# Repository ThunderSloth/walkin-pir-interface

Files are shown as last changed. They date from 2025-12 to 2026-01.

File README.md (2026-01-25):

# Battery-Powered PIR Motion Interface (Isolated Dry Contact)

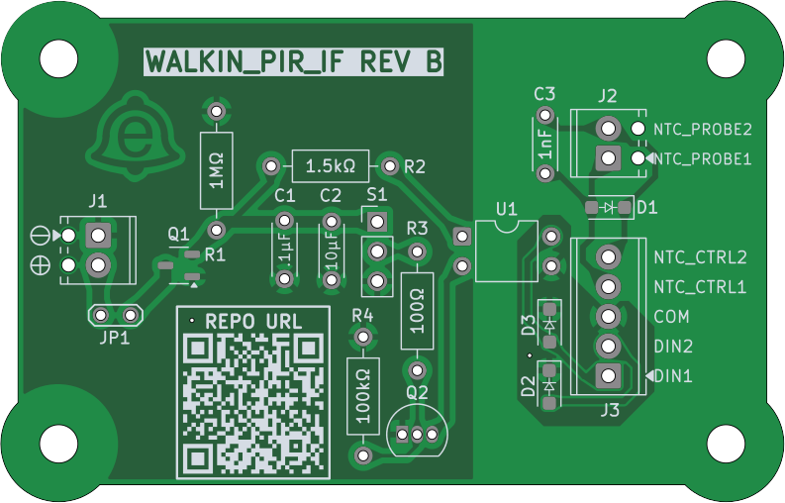
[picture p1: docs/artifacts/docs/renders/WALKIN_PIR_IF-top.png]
Top view PCB render

## Overview
Battery-powered PIR interface designed to trigger **motion-activated overhead lighting** via an **isolated dry input** on an **XWA11V industrial controller**. Intended for installation in a **walk-in cooler** where running mains power to the sensor is undesirable.

The board detects motion using an **AM312 PIR** and signals the controller by closing a **dry contact (DIN ↔ COM)** through a **PhotoMOS relay**. It also provides a **pass-through connection for an external NTC temperature probe**, allowing temperature sensing to share the same cable run.

All lighting logic and power switching are handled by the controller; this board functions as a low-power, robust peripheral.

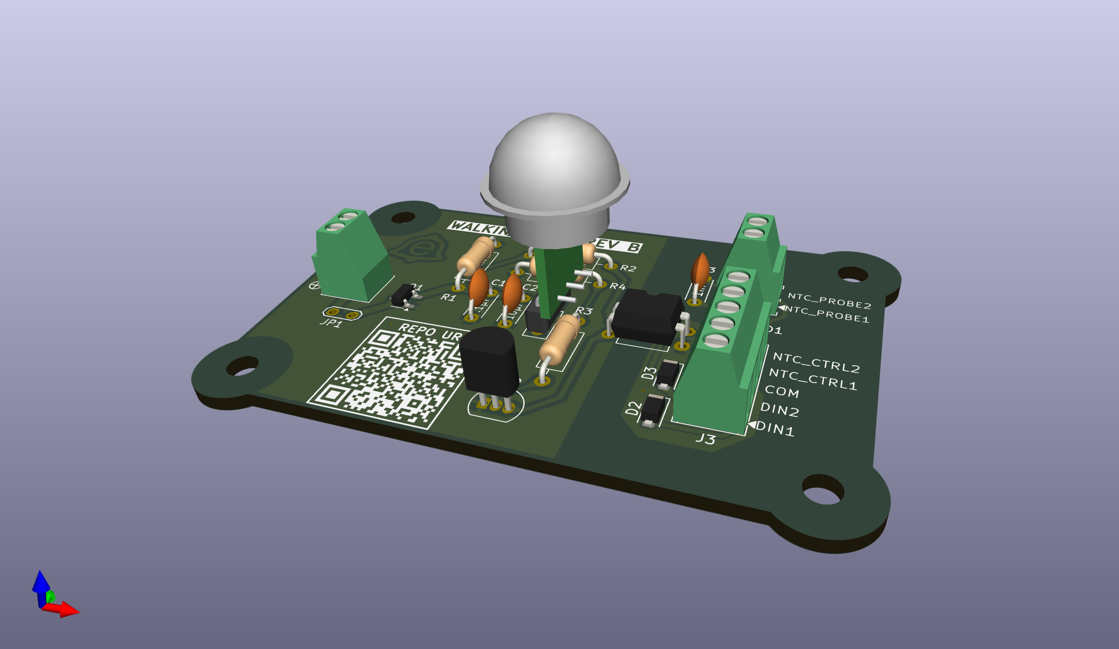
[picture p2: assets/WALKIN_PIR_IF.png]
3D render of WALKIN_PIR_IF PCB


---

## Design Summary
- **Power:** 3×AA battery (targeting multi-month to ~1 year life)
- **Isolation:** PhotoMOS relay provides a true dry contact
- **Protection:**
  - Reverse polarity protection on battery input
  - TVS diodes on all field wiring (DIN, COM, NTC probe)
- **Environment:** Cold (~35–40°F), ~6 ft cable runs
- **Assembly:** Hand-solderable THT + simple SMD parts

---

## Design Rationale
- Battery power avoids mains wiring near the sensor
- PhotoMOS isolation prevents ground loops with industrial controls
- TVS protection improves robustness for long, exposed wiring
- Conservative, low-power design prioritizes reliability over complexity

---

## Hardware Documentation

All design, assembly, and fabrication artifacts are published here:

➡️ [WALKIN_PIR_IF Documentation (MkDocs)](https://thundersloth.github.io/walkin-pir-interface/)

---

## Hardware Status

**Rev B sent to fabrication ✅**  
Simplified prototype validated (video below).

- **Rev A:** PIR output sags under direct PhotoMOS LED drive → unreliable switching.
- **Rev B:** Added NPN low-side driver + LED current-limit resistor to isolate PIR output from load.

[https://github.com/user-attachments/assets/d97296ae-1a20-4d2e-b4a4-3fdf33289da8](https://github.com/user-attachments/assets/c07f9941-2b6e-4c99-ae80-a9b624c08050)

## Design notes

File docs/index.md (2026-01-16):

# WALKIN_PIR_IF — Hardware Documentation

Battery-powered PIR motion interface providing an isolated dry contact output for an industrial controller.

<p class="theme-image">
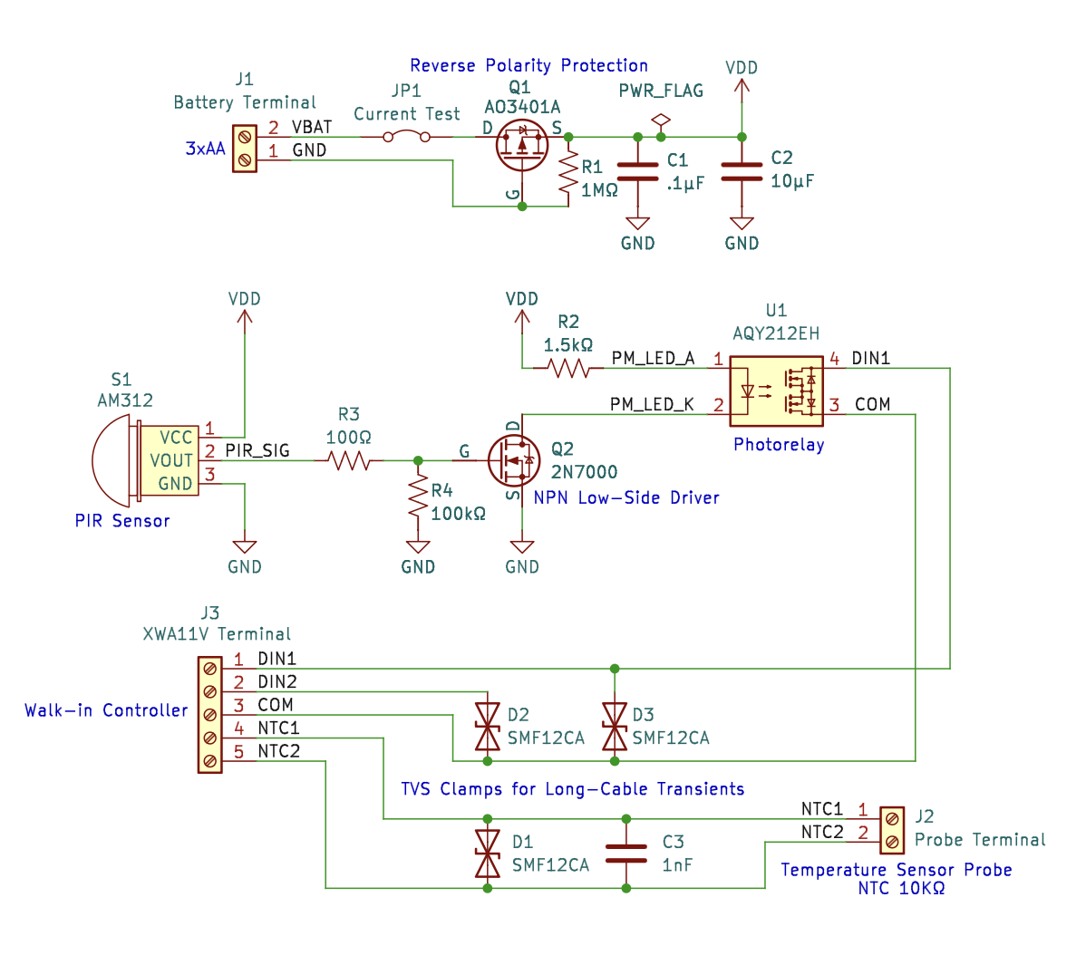
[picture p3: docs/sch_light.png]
WALKIN_PIR_IF schematic (light)
  
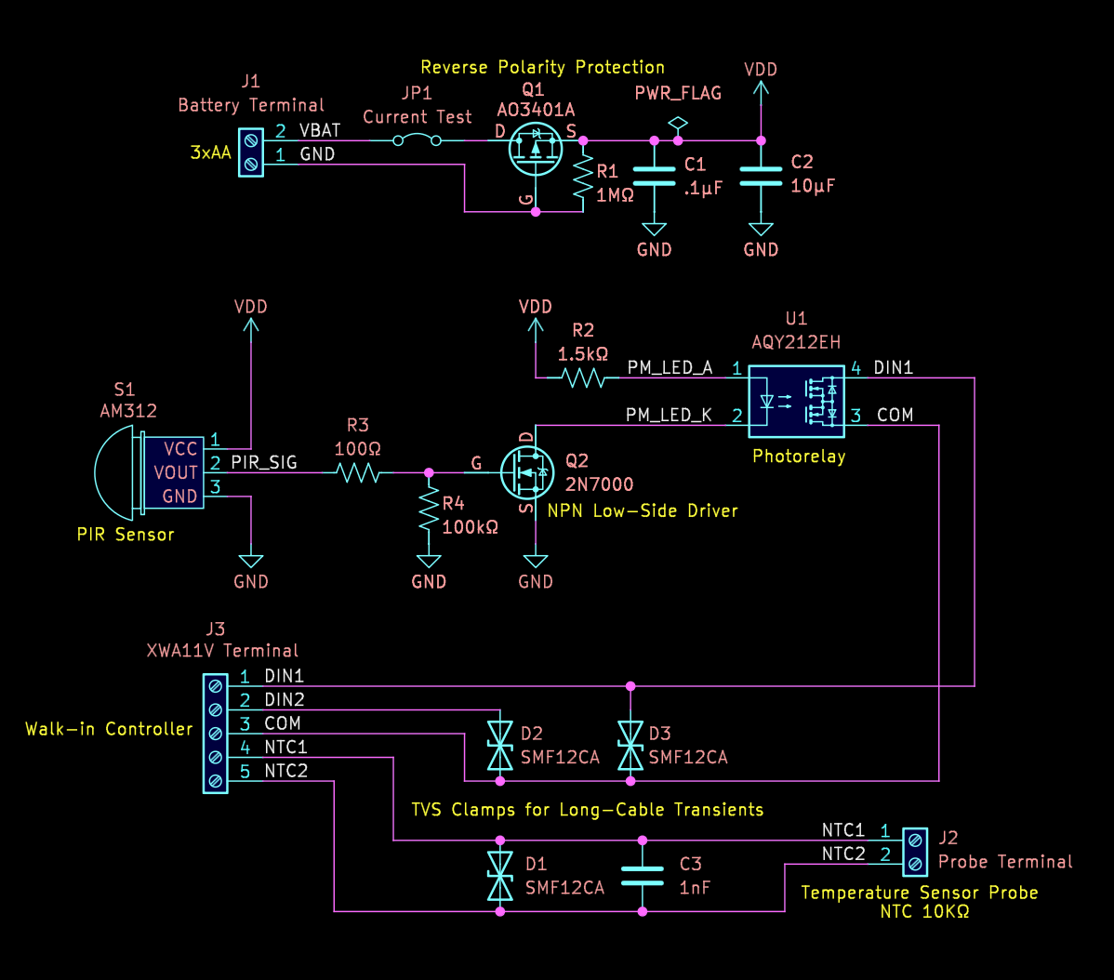
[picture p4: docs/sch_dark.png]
WALKIN_PIR_IF schematic (dark)
  
</p>

This site hosts the complete set of design, assembly, and fabrication artifacts generated from the KiCad project via KiBot.

---

## ℹ️ Project

- **GitHub Repository** [ThunderSloth/walkin-pir-interface](https://github.com/ThunderSloth/walkin-pir-interface)

---

## 📐 Design

- **Schematic (PDF)** [[view]](artifacts/docs/schematic/WALKIN_PIR_IF-schematic.pdf)
- **PCB Render — Top (2D)** [[view]](artifacts/docs/renders/WALKIN_PIR_IF-top.png)
- **PCB Render — Bottom (2D)** [[view]](artifacts/docs/renders/WALKIN_PIR_IF-bottom.png)

---

## 🔧 Assembly

- **Interactive BOM (iBOM)** [[view]](artifacts/docs/ibom/WALKIN_PIR_IF-ibom.html)
- **Bill of Materials (CSV)** [[view]](artifacts/assembly/WALKIN_PIR_IF-bom.csv.html) [[download]](artifacts/assembly/WALKIN_PIR_IF-bom.csv)
- **Pick & Place — Top Side (CSV)** [[view]](artifacts/assembly/WALKIN_PIR_IF-pickplace-top_pos.csv.html) [[download]](artifacts/assembly/WALKIN_PIR_IF-pickplace-top_pos.csv)
- **Assembly Drawing (PDF)** [[view]](artifacts/docs/assembly/WALKIN_PIR_IF-assembly-top.pdf)

---

## ⚙️ Fabrication

- **Fabrication Drawing (PDF)** [[view]](artifacts/docs/fab/WALKIN_PIR_IF-fab-drawing.pdf)
- **Gerbers & Drill Files (ZIP)** [[download]](artifacts/fab/WALKIN_PIR_IF_fab.zip)

---

## 🧊 Mechanical

- **3D STEP Model** [[download]](artifacts/mcad/WALKIN_PIR_IF-3D.step)

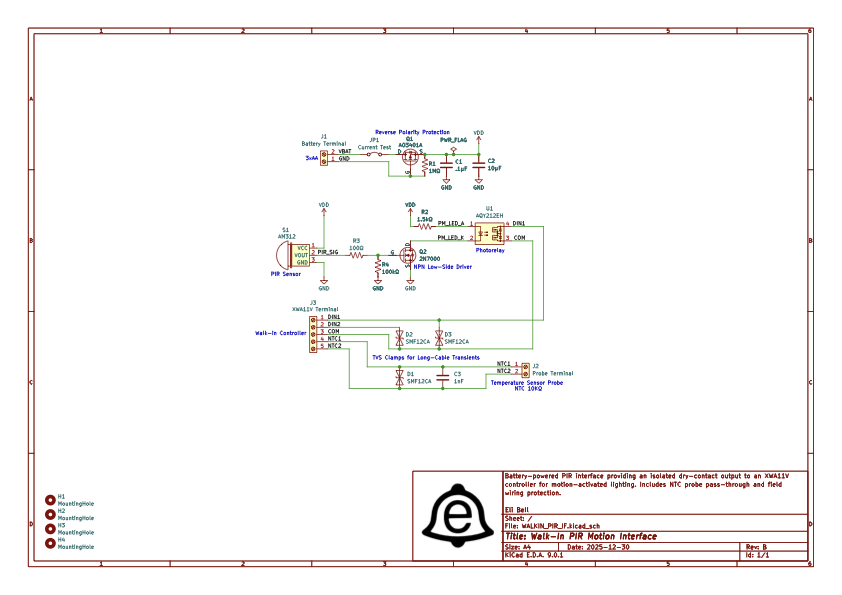
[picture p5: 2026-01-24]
docs/artifacts/previews/schematic.png

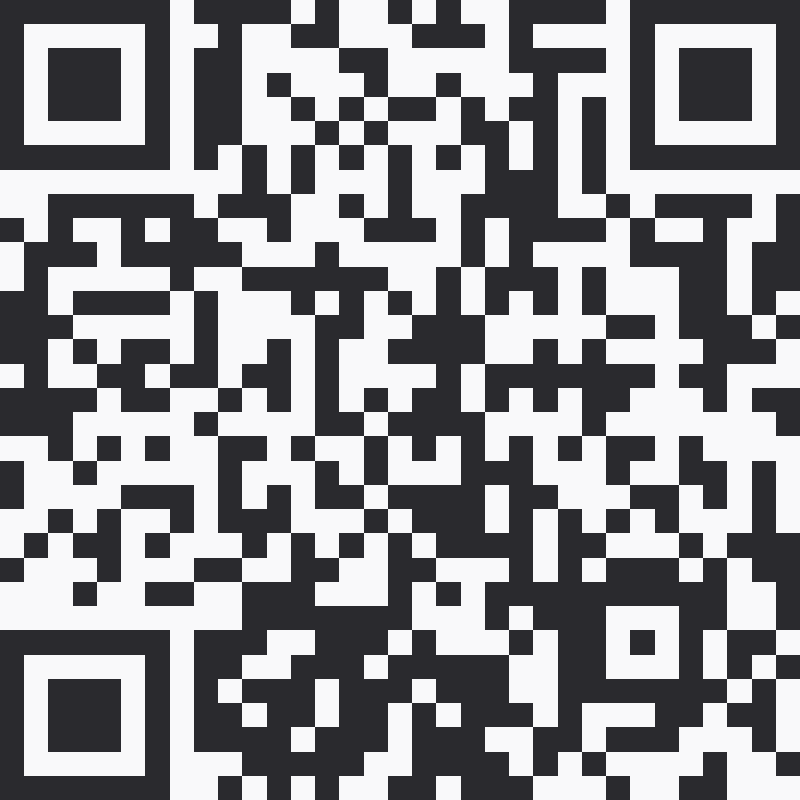
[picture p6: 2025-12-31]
assets/repo_url.png

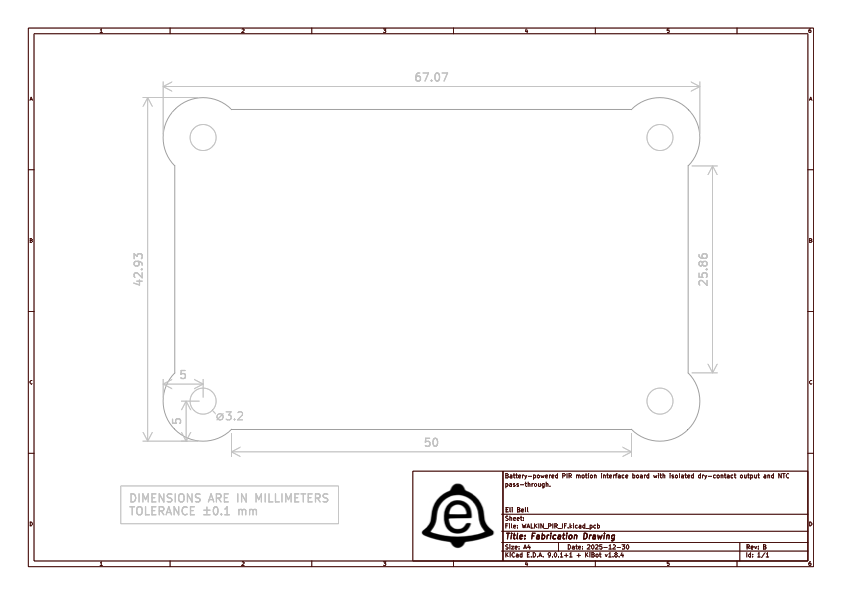
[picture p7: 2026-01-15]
docs/artifacts/previews/fab-drawing.png

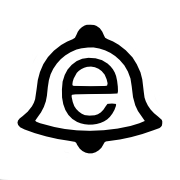
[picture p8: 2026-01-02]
assets/Eli_Bell.jpg

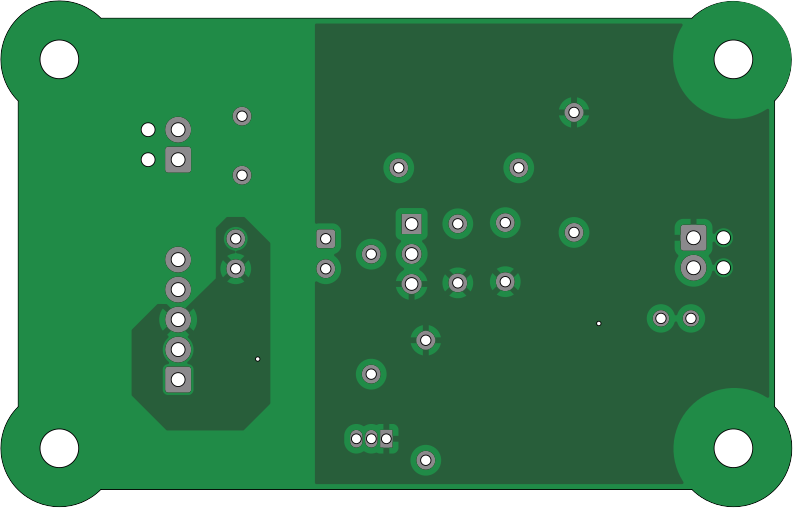
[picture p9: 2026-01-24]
docs/artifacts/docs/renders/WALKIN_PIR_IF-bottom.png

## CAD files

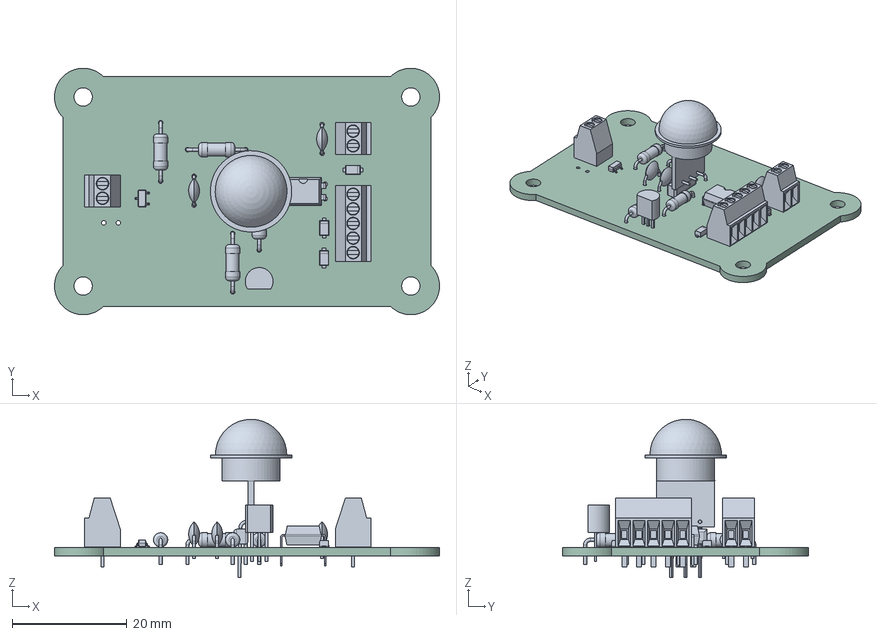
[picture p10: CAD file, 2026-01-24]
docs/artifacts/mcad/WALKIN_PIR_IF-3D.step
67.1 x 42.9 x 27.6 mm
TerminalBlock_Phoenix_MPT-0,5-5-2.54_1x05_P2.54mm_Horizontal
C_Disc_D4.3mm_W1.9mm_P5.00mm x 3
DIP-4_W7.62mm
SOT-23-3
D_SOD-123F x 3
R_Axial_DIN0207_L6.3mm_D2.5mm_P10.16mm_Horizontal_1_0_1
TerminalBlock_Phoenix_MPT-0,5-2-2.54_1x02_P2.54mm_Horizontal x 2
R_Axial_DIN0207_L6.3mm_D2.5mm_P10.16mm_Horizontal_1_0_5
R_Axial_DIN0207_L6.3mm_D2.5mm_P10.16mm_Horizontal_1_5_2
AM312
TO-92_Inline
R_Axial_DIN0207_L6.3mm_D2.5mm_P10.16mm_Horizontal_1_0_4
kibot_5gq1o4dk_PCB

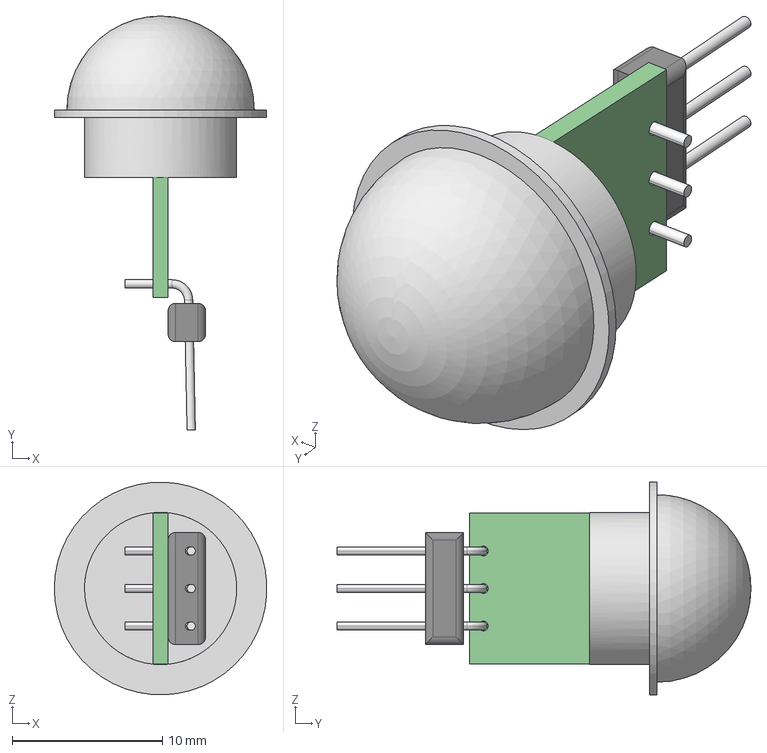
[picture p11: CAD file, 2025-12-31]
hardware/pcb/kicad/3dmodels/AM312.step
14.2 x 27.6 x 14.2 mm

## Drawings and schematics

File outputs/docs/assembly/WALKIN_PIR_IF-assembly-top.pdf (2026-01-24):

67.07

H4

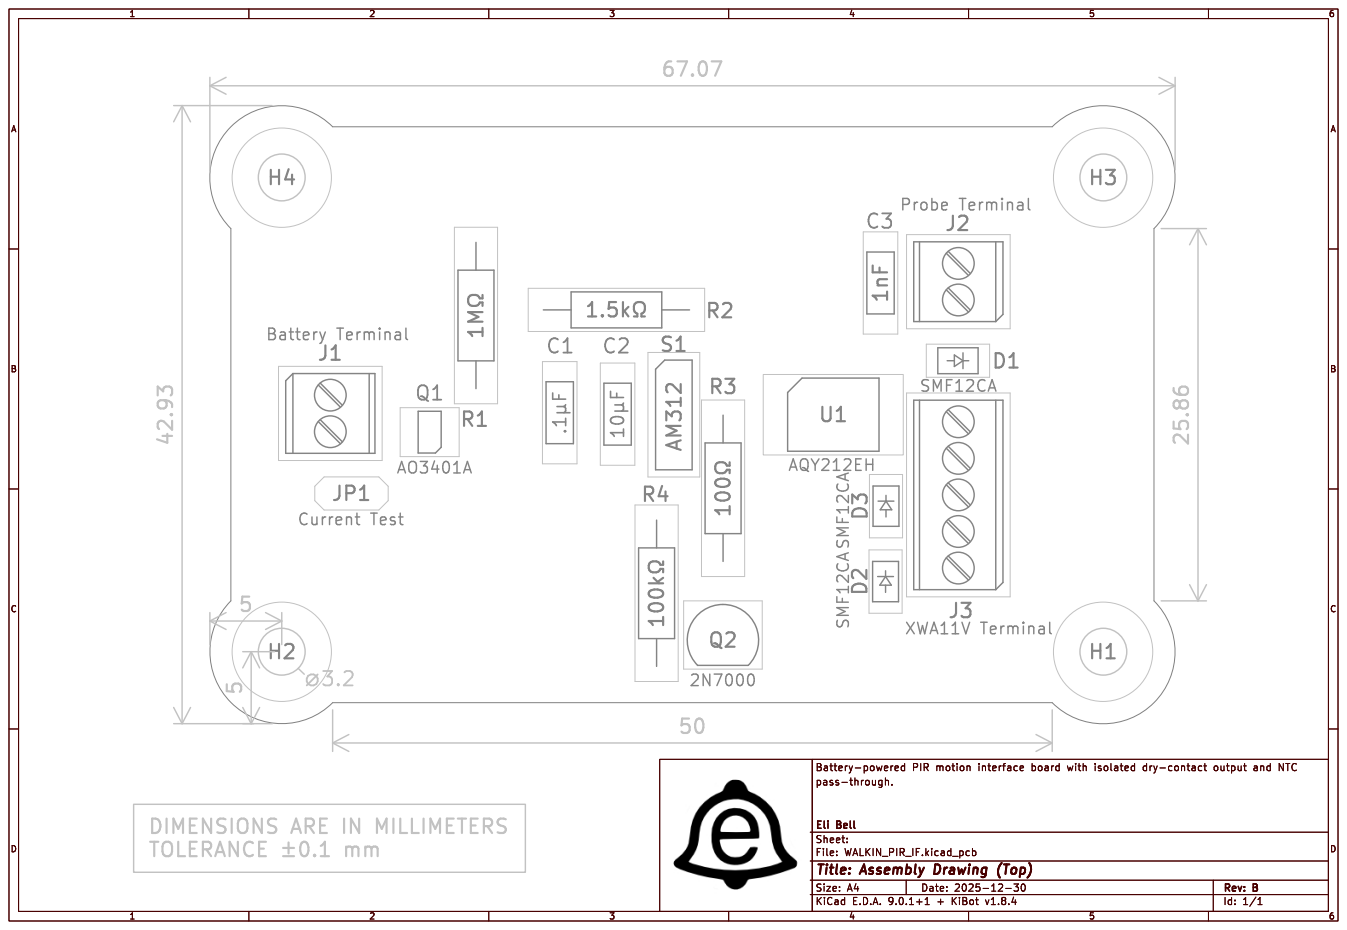
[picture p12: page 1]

Sheet:
File: WALKIN_PIR_IF.kicad_pcb
Title: Assembly Drawing (Top)

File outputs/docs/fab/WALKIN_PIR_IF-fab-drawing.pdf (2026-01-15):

67.07

67.07

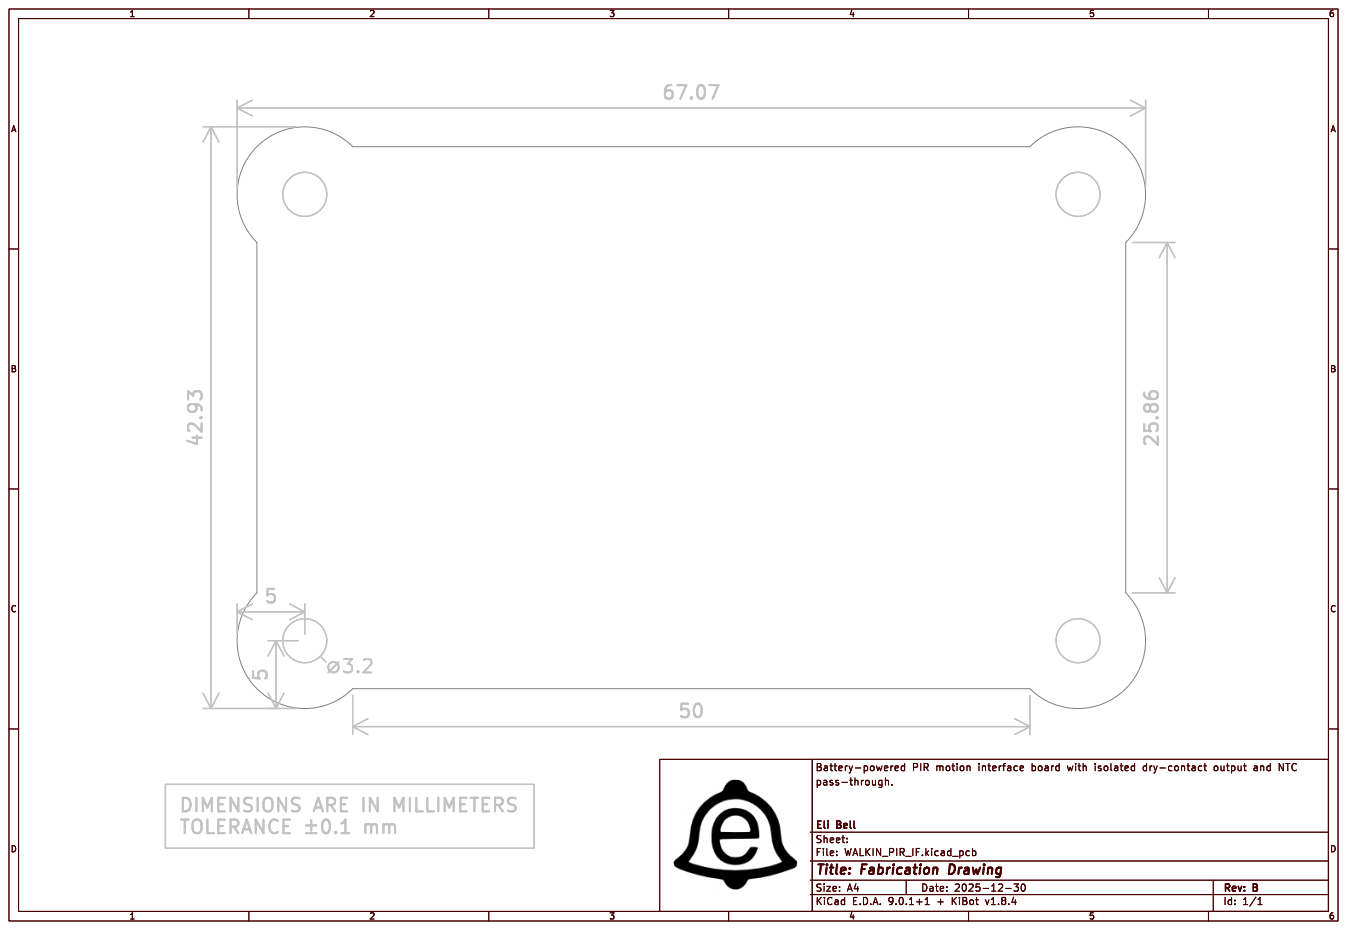
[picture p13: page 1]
Battery-powered; PIR; motion interface board; with isolated dry-contact output and; NTC; pass-through.; Eli; Bell; Size: A4; Rev:; KiCad; E.D.A. 9.0.1+1 + KiBot v1.8.4; Date: 2025-12-30; TOLERANCE; DIMENSIONS; ARE; MILLIMETERS

Sheet:
File: WALKIN_PIR_IF.kicad_pcb
Title: Fabrication Drawing

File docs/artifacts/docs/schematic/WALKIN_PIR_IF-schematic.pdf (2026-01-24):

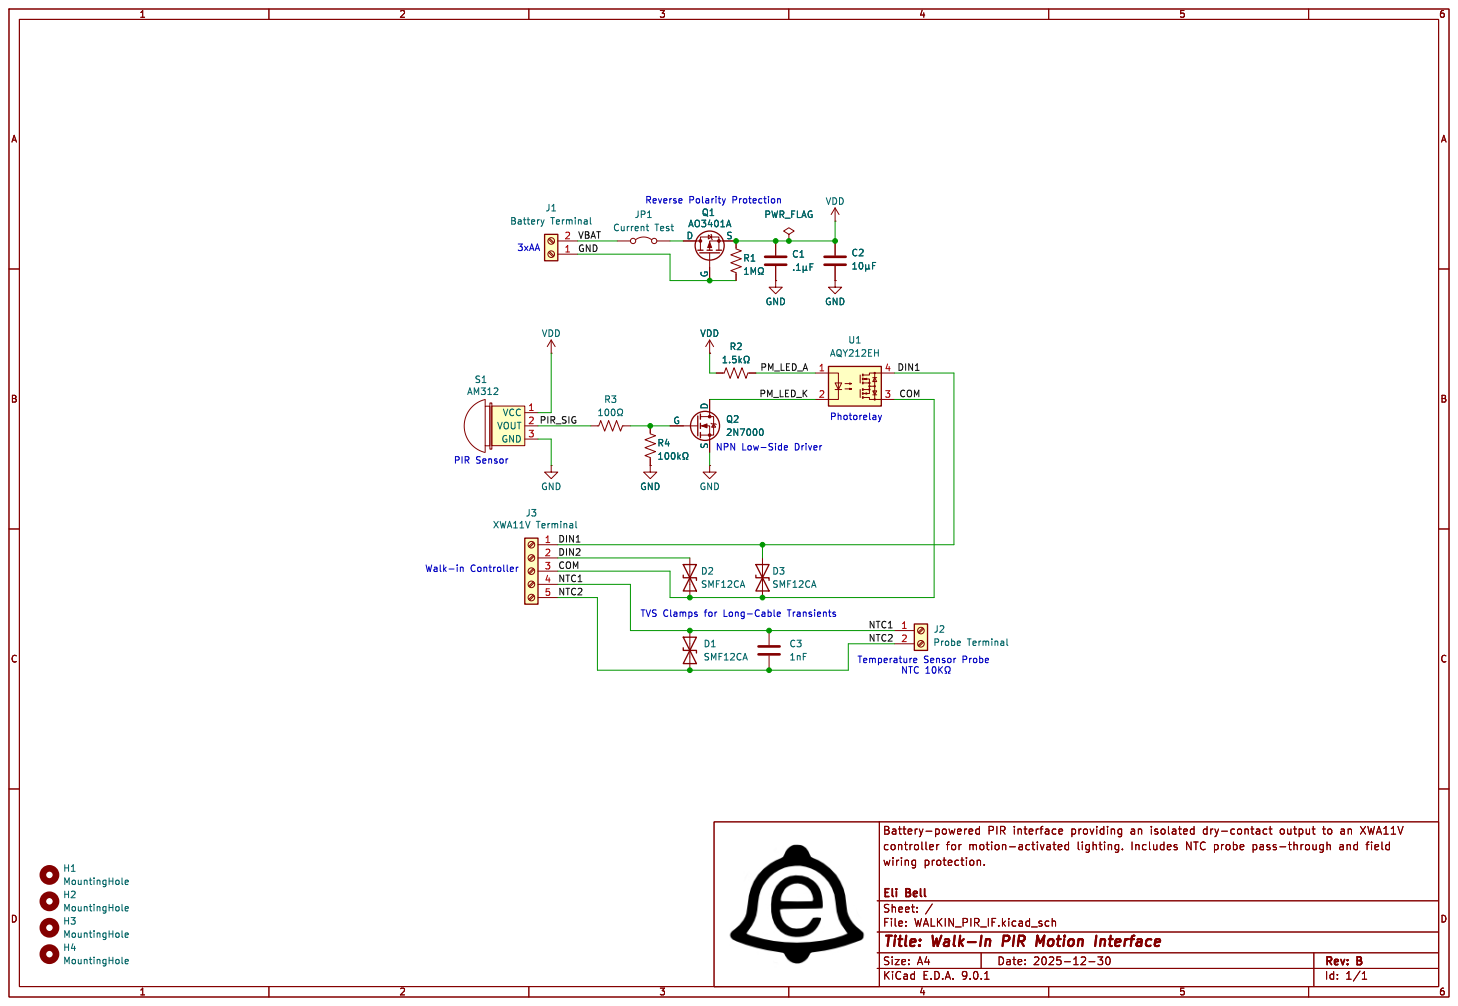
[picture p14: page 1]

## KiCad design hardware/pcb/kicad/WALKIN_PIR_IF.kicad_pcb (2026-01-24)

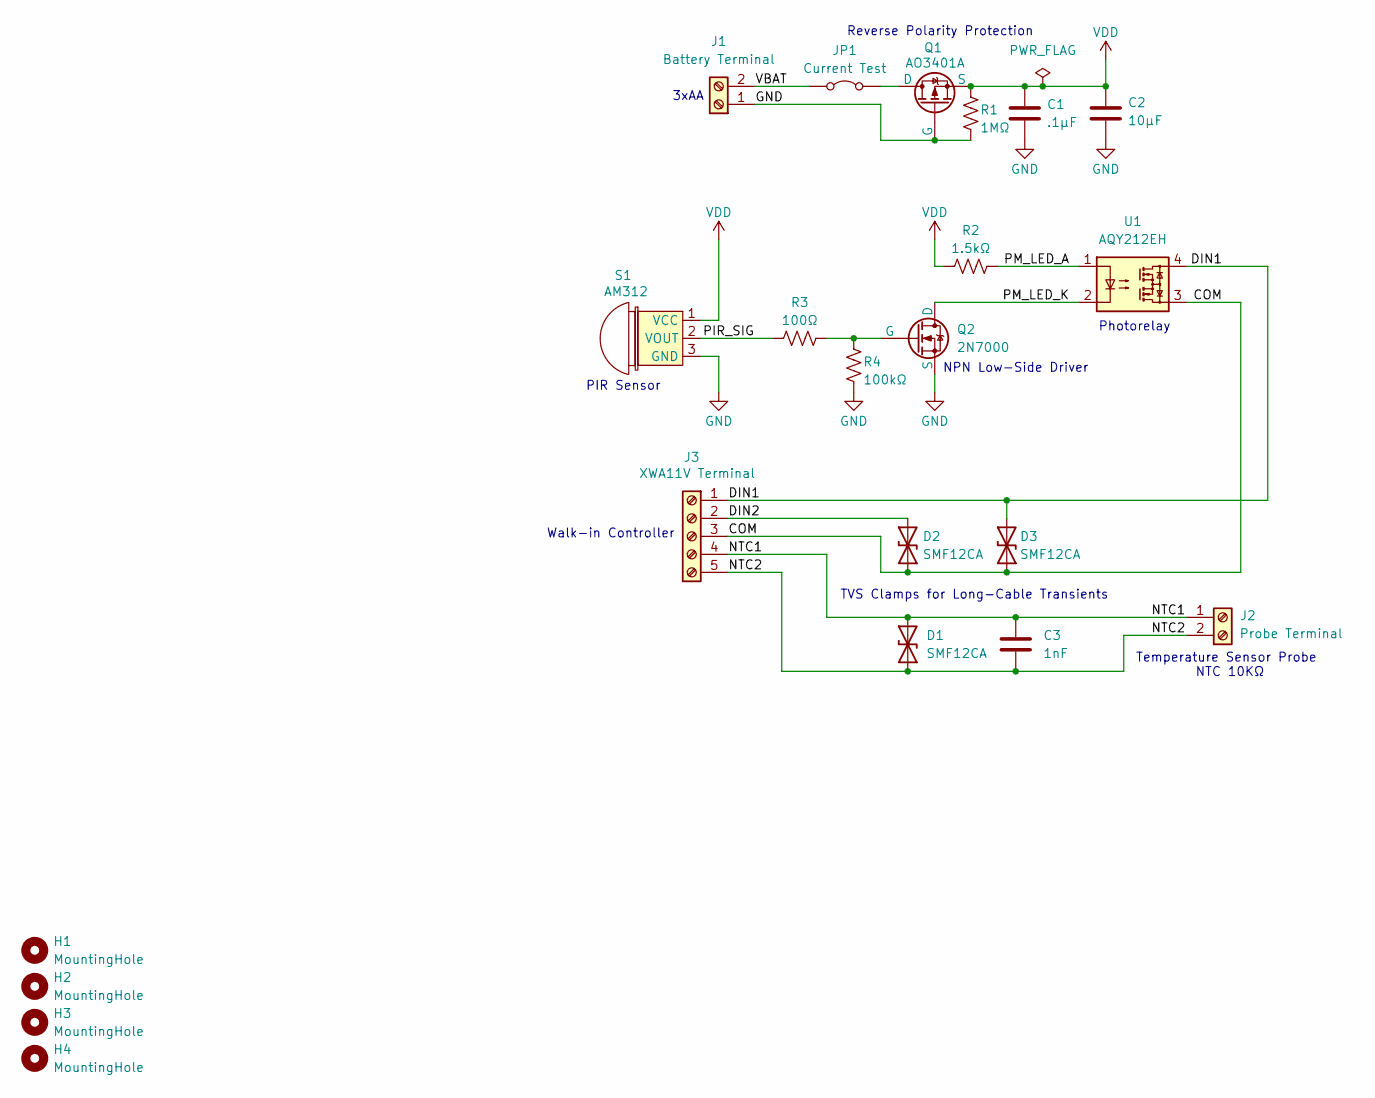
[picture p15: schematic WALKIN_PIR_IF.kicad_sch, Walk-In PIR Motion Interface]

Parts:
C1: .1µF; C_Disc_D4.3mm_W1.9mm_P5.00mm
C2: 10µF; C_Disc_D4.3mm_W1.9mm_P5.00mm
C3: 1nF; C_Disc_D4.3mm_W1.9mm_P5.00mm
D1, D2, D3: SMF12CA; D_SOD-123F
H1, H2, H3, H4: MountingHole; MountingHole_3.2mm_M3
J1: Battery Terminal; TerminalBlock_Phoenix_MPT-0,5-2-2.54_1x02_P2.54mm_Horizontal
J2: Probe Terminal; TerminalBlock_Phoenix_MPT-0,5-2-2.54_1x02_P2.54mm_Horizontal
J3: XWA11V Terminal; TerminalBlock_Phoenix_MPT-0,5-5-2.54_1x05_P2.54mm_Horizontal
JP1: Current Test; TestPoint_2Pads_Pitch2.54mm_Drill0.8mm
Q1: AO3401A; SOT-23-3
Q2: 2N7000; TO-92_Inline
R1: 1MΩ; R_Axial_DIN0207_L6.3mm_D2.5mm_P10.16mm_Horizontal
R2: 1.5kΩ; R_Axial_DIN0207_L6.3mm_D2.5mm_P10.16mm_Horizontal
R3: 100Ω; R_Axial_DIN0207_L6.3mm_D2.5mm_P10.16mm_Horizontal
R4: 100kΩ; R_Axial_DIN0207_L6.3mm_D2.5mm_P10.16mm_Horizontal
S1: AM312; PinHeader_1x03_P2.54mm_Vertical
U1: AQY212EH; DIP-4_W7.62mm

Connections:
/COM: D2.1 (A1), D3.1 (A1), J3.3, U1.3
/DIN1: D3.2 (A2), J3.1, U1.4
/DIN2: D2.2 (A2), J3.2
/NTC1: C3.1, D1.2 (A2), J2.1 (VBAT-), J3.4
/NTC2: C3.2, D1.1 (A1), J2.2 (VBAT+), J3.5
/PIR_SIG: R3.1, S1.2 (VOUT)
/PM_LED_A: R2.2, U1.1
/PM_LED_K: Q2.3 (D), U1.2
/VBAT: J1.2 (VBAT-), JP1.1 (A)
GND: C1.2, C2.2, J1.1 (VBAT+), Q1.1 (G), Q2.1 (S), R1.2, R4.2, S1.3 (GND)
unnamed: JP1.2 (B), Q1.3 (D)
unnamed: Q2.2 (G), R3.2, R4.1
VDD: C1.1, C2.1, Q1.2 (S), R1.1, R2.1, S1.1 (VCC)

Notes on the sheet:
PIR Sensor
TVS Clamps for Long-Cable Transients
Photorelay
3xAA
NTC 10KΩ
Walk-in Controller
Temperature Sensor Probe
NPN Low-Side Driver
Reverse Polarity Protection

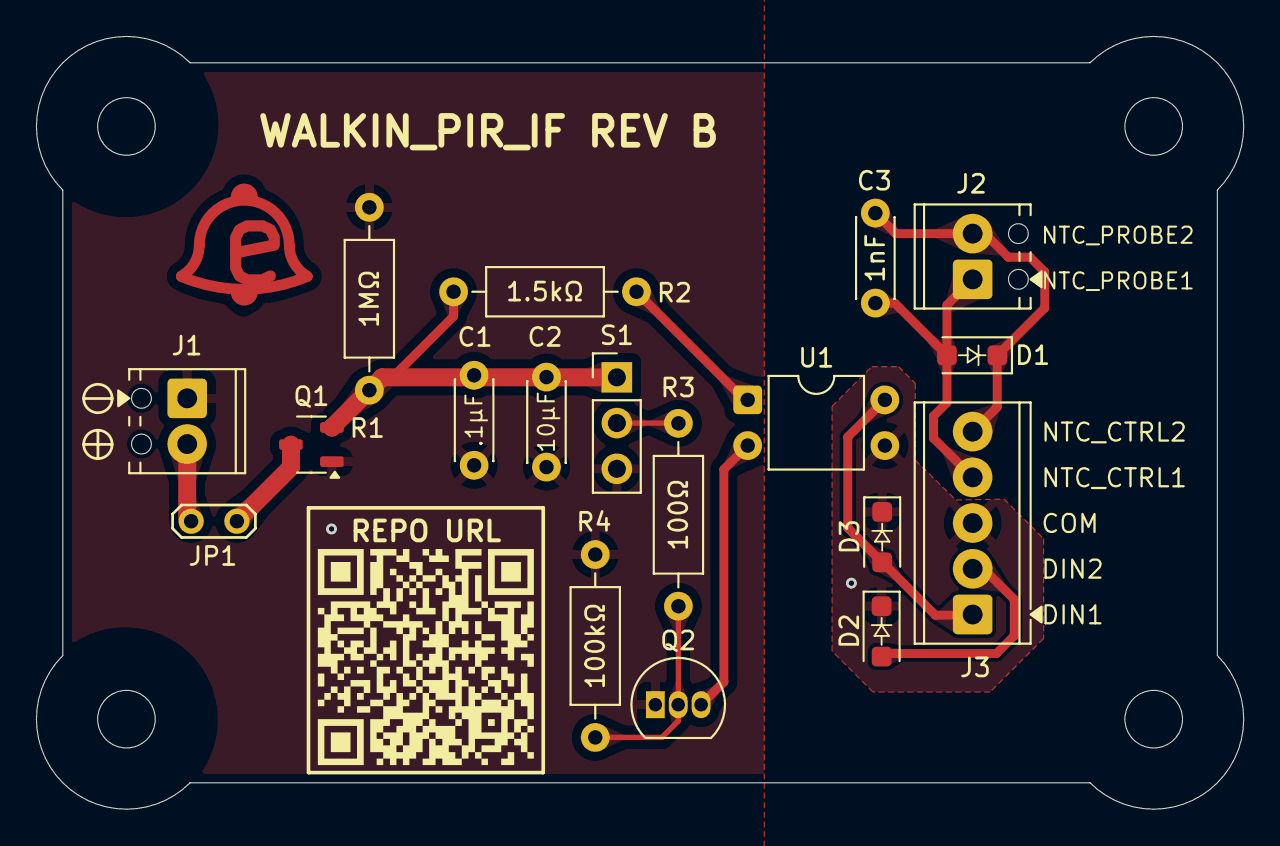
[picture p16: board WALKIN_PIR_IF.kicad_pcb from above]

Board: 2 copper layers, 67.1 x 42.9 mm, 22 parts (0 on the bottom side), 13 nets.

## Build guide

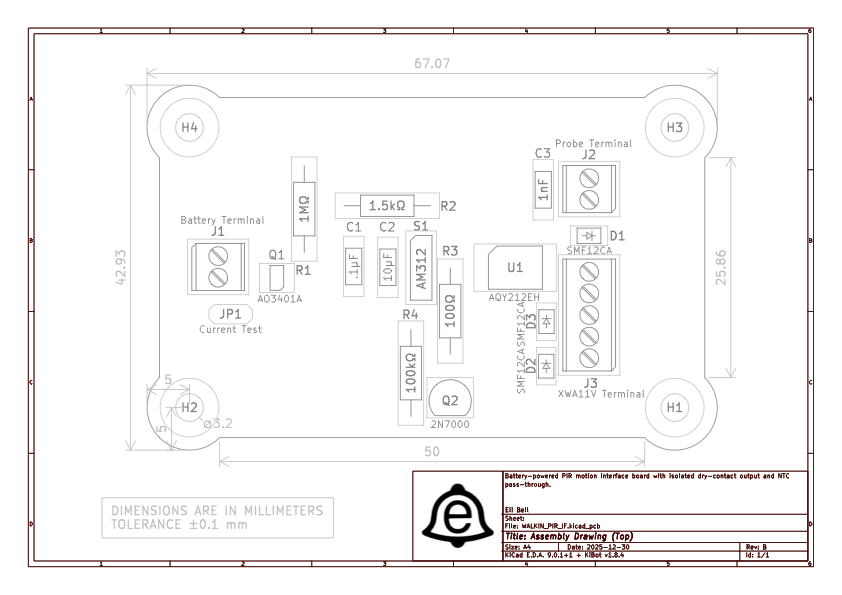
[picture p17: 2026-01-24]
docs/artifacts/previews/assembly-top.png

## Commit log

2025-12-31 fab diagram and 3d render
    [WALKIN_PIR_IF-3D.step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]
2025-12-31 Add 3D render image to README
    Added a 3D render image of the PCB to the README.
2025-12-31 Add 3D render image to README
    Added a 3D render image of the WALKIN_PIR_IF PCB to the README.
2026-01-02 mkdoc init
    [WALKIN_PIR_IF-3D.step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]
2026-01-02 2d renders to png on make
    [WALKIN_PIR_IF-3D.step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]
2026-01-02 2d renders png instead of svg
    [WALKIN_PIR_IF-3D.step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]
2026-01-15 Added npn low side driver for photomos cathode for rev B
    [WALKIN_PIR_IF-3D.step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]
2026-01-16 update repo link text
    [WALKIN_PIR_IF-3D.step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]
2026-01-24 moved pir pulldown r to npn gate and changed value to 100k
    [WALKIN_PIR_IF-3D.step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]
